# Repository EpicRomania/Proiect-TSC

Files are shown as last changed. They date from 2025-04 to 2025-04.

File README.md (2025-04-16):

# Proiect-TSC

## Block Diagram



## ESP32-C6

Microcontrolerul central care coordoneaza procesarea datelor si comunicarea cu modulele.
- Microcontroler RISC-V cu Wi-Fi 6 și Bluetooth LE.
  
**Controleaza interfetele SPI si I2C pentru restul modulelor.**

**Pentru conectarea memoriei externe, sunt folositi urmatorii pini:**

- MOSI  
- MISO  
- SCK  
- CS

**Pentru conectarea ceasului real si a senzorilor, se utilizeaza:**

- SDA  
- SCL

**Pinii de debug si programare sunt accesibili prin interfata dedicata.**

## Memorie Externa

- Conectata prin SPI (MOSI, MISO, SCK, CS). 

- Stocheaza datele e-book si firmware-ul.

## Ceas Real si Module Senzoriale

- Dispozitivele de timp real si senzorii se conecteaza pe pinii SDA si SCL.
- **DS3231** pentru data/ora precisa (RTC).  
- **BME680/BME688** pentru temperatura, umiditate, presiune si VOC (aer). 
- Aceste module asigura sincronizarea si monitorizarea mediului.

## Afisaj E-Paper 
- Controlat prin interfata SPI (linii comune cu memoria externa, dar cu semnal CS separat).  
- Are propriul circuit driver (bobina L2 si componente auxiliare).

## Stocare pe card SD
- Conectat tot pe magistrala SPI pentru extinderea posibilitatilor de stocare

 ## Butoane  
- **Reset** si **Boot** pentru controlul microcontrolerului (reprogramare, reset).
- **Change** – buton suplimentar pentru interactiuni in aplicatie.

## Management Baterie
- **MCP73831** ca incarcator LiPo (5 V din USB-C -> LiPo).  
- **MAX17048** ca monitor de nivel al bateriei (I2C).  
- **USB-C** pentru alimentare, incarcare si, la nevoie, date USB.

## Aspecte de Design

- Componentele sunt asezate astfel incat accesul la conectori sa fie relatic simplu.
- Test pads (TP) sunt disponibile pe fata placii pentru masuratori de semnal si alimentare.  
- Circuitele de protectie ESD si de filtrare sunt incluse pentru USB-C si liniile SPI. 

## Bill of Materials

| Component | Buy Link | Datasheet Link |
|---|---|---|
| ADAFRUIT_LEDCHIP-LED0603 | [Mouser](https://ro.mouser.com/c/optoelectronics/led-lighting/?m=Adafruit) | [Datasheet](https://ro.mouser.com/c/optoelectronics/led-lighting/?m=Adafruit) |
| SJ | [GrabCAD](https://grabcad.com/library/solder-jumpers-1) | [GrabCAD](https://grabcad.com/library/solder-jumpers-1) |
| ESP32_WROVER_EAGLE-LTSPICE_CC0402  | [Mouser](https://ro.mouser.com/c/passive-components/capacitors/ceramic-capacitors/?q=CC0402) | [Datasheet](https://componentsearchengine.com/Datasheets/2/CC0402MRX5R5BB106.pdf) |
| ESP32_WROVER_EAGLE-LTSPICE_RR0402  | [Mouser](https://ro.mouser.com/c/passive-components/resistors/smd-resistors-chip-resistors/?case%20code%20-%20in=0402) | [Datasheet](https://www.yageo.com/upload/media/product/products/datasheet/rchip/PYu-RC_Group_51_RoHS_L_12.pdf) |
| RCL_CPOL-EUCT3528 | [Mouser](https://ro.mouser.com/c/passive-components/antennas/?m=Linx+Technologies&series=RCL) | [Mouser](https://ro.mouser.com/c/passive-components/antennas/?m=Linx+Technologies&series=RCL) |
| 112A-TAAR-R03_ATTEND | [Comet](https://store.comet.srl.ro/Catalogue/Product/43497/) | [SnapEDA](https://www.snapeda.com/parts/112A-TAAR-R03/Attend/datasheet/) |
| DMG2305UX-7 | [DigiKey](https://www.digikey.com/en/products/detail/diodes-incorporated/DMG2305UX-7/4340666) | [Datasheet](https://www.diodes.com/assets/Datasheets/DMG2305UX.pdf) |
| 744043680IND_4828-WE-TPC_WRE | [Mouser](https://ro.mouser.com/ProductDetail/Wurth-Elektronik/744043680?qs=PGXP4M47uW6VkZq%252BkzjrHA%3D%3D)  | [Datasheet](https://www.we-online.com/components/products/datasheet/744043680.pdf) |
| BME680 | [Mouser](https://ro.mouser.com/ProductDetail/Bosch-Sensortec/BME688?qs=IS%252B4QmGtzzqQoVDscqwx3A%3D%3D) | [Datasheet](https://ro.mouser.com/datasheet/2/783/bst_bme688_fl000-2307034.pdf) |
| BUTTON_CUSYOMV1 | [Panasonic](https://industry.panasonic.com/global/en/products/control/switch/light-touch/number/evqpuj02k) | [Datasheet](https://industry.panasonic.com/global/en/downloads?tab=catalog&small_g_cd=203&part_no=EVQPUJ02K) |
| DS3231SN# | [Mouser](https://ro.mouser.com/ProductDetail/Analog-Devices-Maxim-Integrated/DS3231SN?qs=1eQvB6Dk1vhUlr8%2FOrV0Fw%3D%3D) | [Datasheet](https://ro.mouser.com/datasheet/2/609/DS3231-3421123.pdf) |
| ESP32-C6-WROOM-1-N8 | [Mouser](https://ro.mouser.com/ProductDetail/Espressif-Systems/ESP32-C6-WROOM-1-N8?qs=8Wlm6%252BaMh8ST02Gmwp74cw%3D%3D) | [Datasheet](https://ro.mouser.com/datasheet/2/891/Espressif_ESP32_C6_WROOM_1__Datasheet_V0_1_PRELIMI-3239987.pdf) |
| ESP32C6_VARISTORCN1812 | [Mouser](https://ro.mouser.com/c/circuit-protection/varistors/?package=1812) | [Mouser](https://ro.mouser.com/c/circuit-protection/varistors/?package=1812) |
| SD0805S020S1R0 | [Mouser](https://ro.mouser.com/ProductDetail/KYOCERA-AVX/SD0805S020S1R0?qs=jCA%252BPfw4LHbpkAoSnwrdjw%3D%3D)  | [Datasheet](https://ro.mouser.com/datasheet/2/40/schottky-3165252.pdf) |
| MCP73831 | [Mouser](https://ro.mouser.com/ProductDetail/Microchip-Technology/MCP73831T-2ATI-OT?qs=yUQqVecv4qsZbioEUu%252B83g%3D%3D) | [Datasheet](https://ro.mouser.com/datasheet/2/268/MCP73831_Family_Data_Sheet_DS20001984H-3441711.pdf) |

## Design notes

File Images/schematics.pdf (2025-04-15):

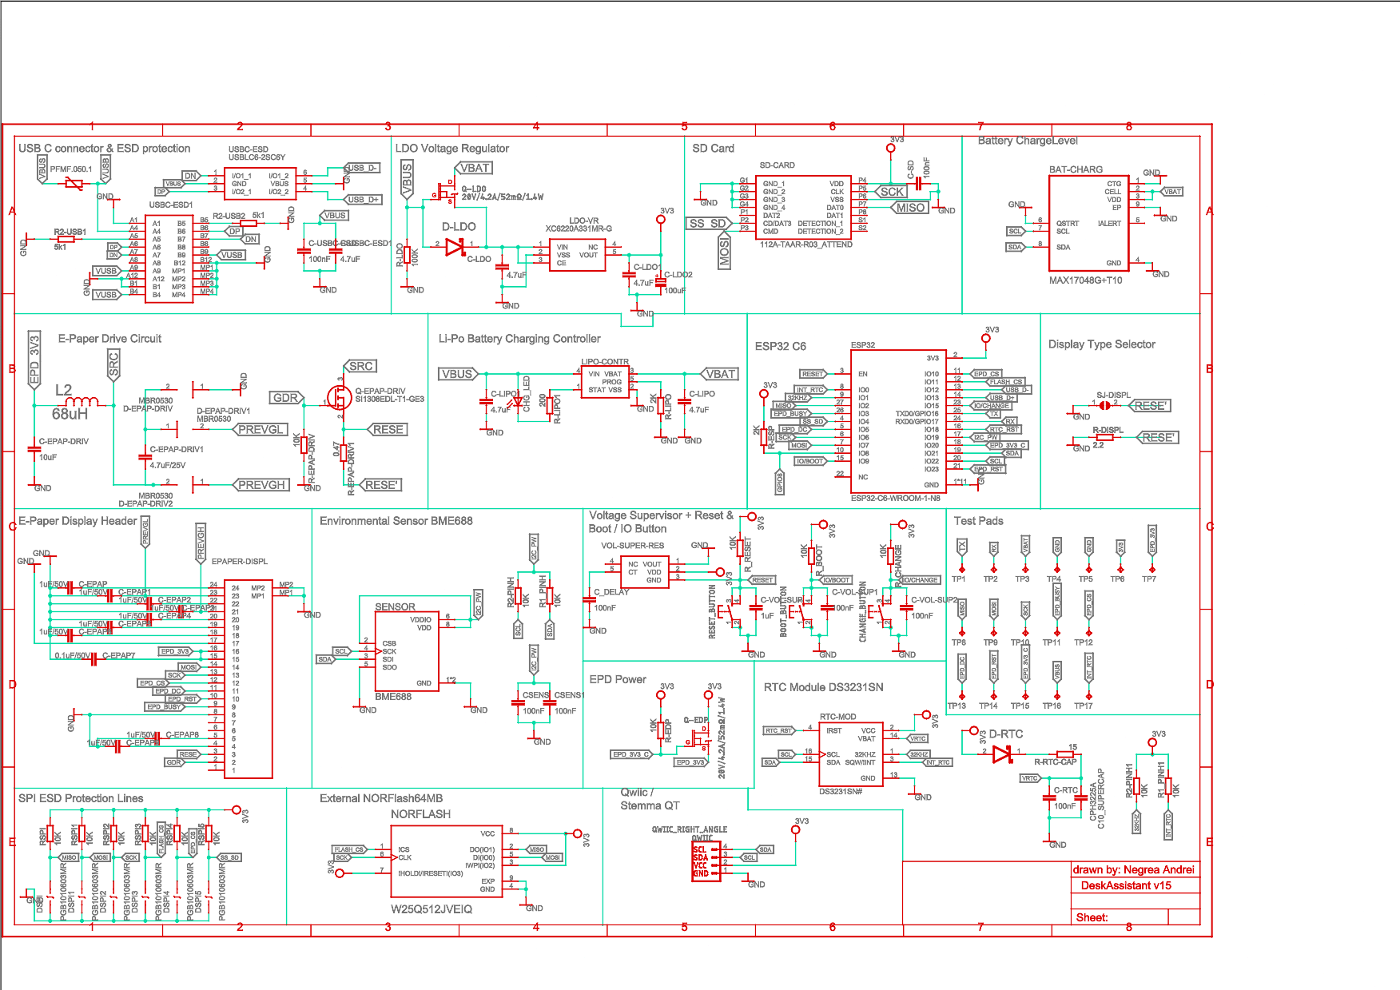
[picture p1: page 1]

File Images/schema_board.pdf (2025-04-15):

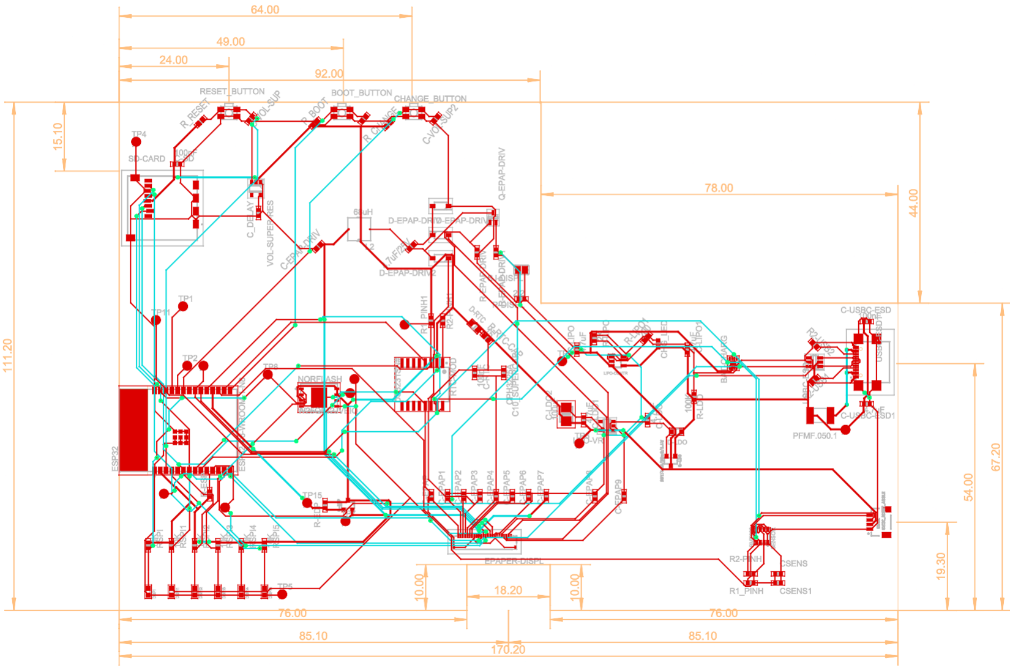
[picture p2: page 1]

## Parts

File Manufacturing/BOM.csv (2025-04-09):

Qty | Value | Device | Package | Parts | Description | ARROW_PART_NUMBER | ARROW_PRICE-STOCK | AVAILABILITY | CENTROID_NOT_SPECIFIED | CHECK_PRICES | COPYRIGHT | DATASHEET | DESCRIPTION | DIGIKEY_DESCRIPTION | DIGIKEY_PART_NUMBER | HEIGHT | LEAD_FREE | MANUFACTURER_NAME | MANUFACTURER_PART_NUMBER | MF | MFR_NAME | MOUSER_PART_NUMBER | MOUSER_PRICE-STOCK | MOUSER_TESTING_PART_NUMBER | MOUSER_TESTING_PRICE-STOCK | MP | MPN | PACKAGE | POPULARITY | PREFIX | PRICE | PROD_ID | PURCHASE-URL | ROHS | SNAPEDA_LINK | SPICEMODEL | SPICEPREFIX | TEMPERATURE_RANGE_HIGH | TEMPERATURE_RANGE_LOW | TP_SIGNAL_NAME | VALUE
1 |  | ADAFRUIT_LEDCHIP-LED0603 | ADAFRUIT_CHIP-LED0603 | CHG_LED | LED
1 |  | SJ | SJ | SJ-DISPL | SMD solder JUMPER |  |  |  |  |  |  |  |  |  |  |  |  |  |  |  |  |  |  |  |  |  |  |  | 3
1 | 0.1uF/50V | ESP32_WROVER_EAGLE-LTSPICE_CC0402 | ESP32_WROVER_EAGLE-LTSPICE_C0402 | C-EPAP7 | CAPACITOR, European symbol |  |  |  |  |  |  |  |  |  |  |  |  |  |  |  |  |  |  |  |  |  |  |  |  |  |  |  |  |  |  | NONE | C
1 | 0.47 | ESP32_WROVER_EAGLE-LTSPICE_RR0402 | ESP32_WROVER_EAGLE-LTSPICE_R0402 | R-EPAP-DRIV1 | RESISTOR, European symbol |  |  |  |  |  |  |  |  |  |  |  |  |  |  |  |  |  |  |  |  |  |  |  |  |  |  |  |  |  |  | NONE | R
1 | 100K | ESP32_WROVER_EAGLE-LTSPICE_RR0402 | ESP32_WROVER_EAGLE-LTSPICE_R0402 | R-LDO | RESISTOR, European symbol |  |  |  |  |  |  |  |  |  |  |  |  |  |  |  |  |  |  |  |  |  |  |  |  |  |  |  |  |  |  | NONE | R
8 | 100nF | ESP32_WROVER_EAGLE-LTSPICE_CC0402 | ESP32_WROVER_EAGLE-LTSPICE_C0402 | C-RTC, C-SD, C-USBC-ESD, C-VOL-SUP1, C-VOL-SUP2, CSENS, CSENS1, C_DELAY | CAPACITOR, European symbol |  |  |  |  |  |  |  |  |  |  |  |  |  |  |  |  |  |  |  |  |  |  |  |  |  |  |  |  |  |  | NONE | C
1 | 100uF | RCL_CPOL-EUCT3528 | RCL_CT3528 | C-LDO2 | POLARIZED CAPACITOR, European symbol |  |  |  |  |  |  |  |  |  |  |  |  |  |  |  |  |  |  |  |  |  |  |  | 0 |  |  |  |  |  |  |  | C
15 | 10K | ESP32_WROVER_EAGLE-LTSPICE_RR0402 | ESP32_WROVER_EAGLE-LTSPICE_R0402 | R-EDP, R-EPAP-DRIV, R1_PINH, R1_PINH1, R2-PINH, R2-PINH1, RSPI, RSPI1, RSPI2, RSPI3, RSPI4, RSPI5, R_BOOT, R_CHANGE, R_RESET | RESISTOR, European symbol |  |  |  |  |  |  |  |  |  |  |  |  |  |  |  |  |  |  |  |  |  |  |  |  |  |  |  |  |  |  | NONE | R
1 | 10uF | ESP32_WROVER_EAGLE-LTSPICE_CC0402 | ESP32_WROVER_EAGLE-LTSPICE_C0402 | C-EPAP-DRIV | CAPACITOR, European symbol |  |  |  |  |  |  |  |  |  |  |  |  |  |  |  |  |  |  |  |  |  |  |  |  |  |  |  |  |  |  | NONE | C
1 | 112A-TAAR-R03_ATTEND | 112A-TAAR-R03_ATTEND | 112ATAARR03ATTEND | SD-CARD | Micro SD Card Socket, Push-Push Type, Top Mount, SMT, H=1.83mm, 10u |  |  |  |  |  |  |  | Micro SD Card Socket | Push-Push Type | Top Mount | SMT | H=1.83mm | 10u |  |  | 1.9mm |  | ATTEND | 112A-TAAR-R03 ATTEND
1 | 15 | ESP32_WROVER_EAGLE-LTSPICE_RR0402 | ESP32_WROVER_EAGLE-LTSPICE_R0402 | R-RTC-CAP | RESISTOR, European symbol |  |  |  |  |  |  |  |  |  |  |  |  |  |  |  |  |  |  |  |  |  |  |  |  |  |  |  |  |  |  | NONE | R
1 | 1uF | ESP32_WROVER_EAGLE-LTSPICE_CC0402 | ESP32_WROVER_EAGLE-LTSPICE_C0402 | C-VOL-SUP | CAPACITOR, European symbol |  |  |  |  |  |  |  |  |  |  |  |  |  |  |  |  |  |  |  |  |  |  |  |  |  |  |  |  |  |  | NONE | C
9 | 1uF/50V | ESP32_WROVER_EAGLE-LTSPICE_CC0402 | ESP32_WROVER_EAGLE-LTSPICE_C0402 | C-EPAP, C-EPAP1, C-EPAP2, C-EPAP3, C-EPAP4, C-EPAP5, C-EPAP6, C-EPAP8, C-EPAP9 | CAPACITOR, European symbol |  |  |  |  |  |  |  |  |  |  |  |  |  |  |  |  |  |  |  |  |  |  |  |  |  |  |  |  |  |  | NONE | C
1 | 2.2 | ESP32_WROVER_EAGLE-LTSPICE_RR0402 | ESP32_WROVER_EAGLE-LTSPICE_R0402 | R-DISPL | RESISTOR, European symbol |  |  |  |  |  |  |  |  |  |  |  |  |  |  |  |  |  |  |  |  |  |  |  |  |  |  |  |  |  |  | NONE | R
1 | 200 | ESP32_WROVER_EAGLE-LTSPICE_RR0402 | ESP32_WROVER_EAGLE-LTSPICE_R0402 | R-LIPO1 | RESISTOR, European symbol |  |  |  |  |  |  |  |  |  |  |  |  |  |  |  |  |  |  |  |  |  |  |  |  |  |  |  |  |  |  | NONE | R
2 | 20V/4.2A/52mO/1.4W | ESP32_WROVER_SPARKFUN-DISCRETESEMI_MOSFET_PCH-DMG2305UX-7 | ESP32_WROVER_SPARKFUN-DISCRETESEMI_SOT23-3 | Q-EDP, Q-LDO | P-channel MOSFETs |  |  |  |  |  |  |  |  |  |  |  |  |  |  |  |  |  |  |  |  |  |  |  |  |  |  | TRAN-14388 |  |  |  |  |  |  |  |  | 20V/4.2A/52mO/1.4W
2 | 2K | ESP32_WROVER_EAGLE-LTSPICE_RR0402 | ESP32_WROVER_EAGLE-LTSPICE_R0402 | R-ESP, R-LIPO | RESISTOR, European symbol |  |  |  |  |  |  |  |  |  |  |  |  |  |  |  |  |  |  |  |  |  |  |  |  |  |  |  |  |  |  | NONE | R
5 | 4.7uF | ESP32_WROVER_EAGLE-LTSPICE_CC0402 | ESP32_WROVER_EAGLE-LTSPICE_C0402 | C-LDO, C-LDO1, C-LIPO, C-LIPO1, C-USBC-ESD1 | CAPACITOR, European symbol |  |  |  |  |  |  |  |  |  |  |  |  |  |  |  |  |  |  |  |  |  |  |  |  |  |  |  |  |  |  | NONE | C
1 | 4.7uF/25V | ESP32_WROVER_EAGLE-LTSPICE_CC0402 | ESP32_WROVER_EAGLE-LTSPICE_C0402 | C-EPAP-DRIV1 | CAPACITOR, European symbol |  |  |  |  |  |  |  |  |  |  |  |  |  |  |  |  |  |  |  |  |  |  |  |  |  |  |  |  |  |  | NONE | C
2 | 5k1 | ESP32_WROVER_EAGLE-LTSPICE_RR0402 | ESP32_WROVER_EAGLE-LTSPICE_R0402 | R2-USB1, R2-USB2 | RESISTOR, European symbol |  |  |  |  |  |  |  |  |  |  |  |  |  |  |  |  |  |  |  |  |  |  |  |  |  |  |  |  |  |  | NONE | R
1 | 68uH | 744043680IND_4828-WE-TPC_WRE | IND_4828-WE-TPC_WRE | L2 |  |  |  |  |  |  | Copyright (C) 2024 Ultra Librarian. All rights reserved. |  |  |  |  |  |  |  | 744043680 |  | Wurth Electronics
1 | BME688 | ESP32_WROVER_BME680_BME680 | ESP32_WROVER_BME680_PSON80P300X300X100-8N | SENSOR | Integrated Environmental Unit |  |  | Unavailable |  |  |  |  | Integrated Environmental Unit |  |  |  |  |  |  | Bosch Sensortec |  |  |  |  |  | BME680 |  | LGA-8 Bosch Tools |  |  | None
1 | BOOT_BUTTON | BUTTON_CUSYOMV1 | MYBUTTON | BOOT_BUTTON
1 | C10_SUPERCAP | ESP32_WROVER_EAGLE-LTSPICE_CC0402 | ESP32_WROVER_EAGLE-LTSPICE_C0402 | CPH3225A | CAPACITOR, European symbol |  |  |  |  |  |  |  |  |  |  |  |  |  |  |  |  |  |  |  |  |  |  |  |  |  |  |  |  |  |  | NONE | C
1 | CHANGE_BUTTON | BUTTON_CUSYOMV1 | MYBUTTON | CHANGE_BUTTON
1 | DS3231SN# | DS3231SN# | SOIC127P1032X265-16N | RTC-MOD | Real Time Clock Serial 16-Pin SOIC W T/R Check availability |  |  | In Stock |  | https://www.snapeda.com/parts/DS3231SN%23/Analog+Devices/view-part/?ref=eda |  |  | Extremely Accurate I²C-Integrated RTC/TCXO/Crystal |  |  |  |  |  |  | Analog Devices |  |  |  |  |  | DS3231SN# |  | SOIC-16 Maxim |  |  | None |  | https://www.snapeda.com/api/url_track_click_mouser/?unipart_id=99048&manufacturer=Analog Devices&part_name=DS3231SN#&search_term=None |  | https://www.snapeda.com/parts/DS3231SN%23/Analog+Devices/view-part/?ref=snap
1 | ESP32-C6-WROOM-1-N8 | ESP32-C6-WROOM-1-N8 | XCVR_ESP32-C6-WROOM-1-N8 | ESP32 | Check availability |  |  | In Stock |  | https://www.snapeda.com/parts/ESP32-C6-WROOM-1-N8/Espressif+Systems/view-part/?ref=eda |  |  | Multiprotocol Modules ESP32-C6 module | Wi-Fi 6 in 2.4 GHz band | Bluetooth 5 | Zigbee 3.0 and Thread. ESP34-WROOM Compatible - ENGINEERING SAMPLE |  |  |  |  |  |  | Espressif Systems |  |  |  |  |  | ESP32-C6-WROOM-1-N8 |  | None |  |  | None |  |  |  | https://www.snapeda.com/parts/ESP32-C6-WROOM-1-N8/Espressif+Systems/view-part/?ref=snap
1 | ESP32C6_VARISTORCN1812 | ESP32C6_VARISTORCN1812 | ESP32C6_VARISTOR_CT/CN1812 | PFMF.050.1 | VARISTOR |  |  |  |  |  |  |  |  |  |  |  |  |  |  |  |  |  |  |  |  |  |  |  | 0
2 | ESP32_WROVER_AVX---SD0805S020S1R0_AVX_SD0805S020S1R0_0_0AVX_SD0805S020S1R0_0_0 | ESP32_WROVER_AVX---SD0805S020S1R0_AVX_SD0805S020S1R0_0_0AVX_SD0805S020S1R0_0_0 | ESP32_WROVER_AVX---SD0805S020S1R0_AVX_SD0805S020S1R0_0 | D-LDO, D-RTC | Schottky Barrier Rectifier Diode |  |  |  | No |  |  | http://datasheets.avx.com/schottky.pdf |  | DIODE SCHOTTKY 20V 1A 0805 | 478-7800-1-ND |  | yes |  |  | AVX |  | 581-SD0805S020S1R0 |  |  |  |  |  | 0805 (2012 metric) |  | D |  |  |  | yes |  |  |  | +125°C | -55°C
1 | ESP32_WROVER_SPARKFUN-IC-POWER_MCP73831 | ESP32_WROVER_SPARKFUN-IC-POWER_MCP73831 | ESP32_WROVER_SPARKFUN-IC-POWER_SOT23-5 | LIPO-CONTR | MCP73831T Li-Ion, Li-Pol Controller |  |  |  |  |  |  |  |  |  |  |  |  |  |  |  |  |  |  |  |  |  |  |  |  |  |  | IC-09995
1 | FH34SRJ-24S-0.5SH_99_ | FH34SRJ-24S-0.5SH_99_ | FH34SRJ24S05SH99 | EPAPER-DISPL | (0.50mm) Surface Mount, Right Angle |  |  |  |  |  |  |  | 24 Position FFC | FPC Connector Contacts | (0.50mm) Surface Mount | Right Angle |  |  | 1.1mm |  | Hirose | FH34SRJ-24S-0.5SH(99) |  |  | 798-FH34SRJ24S05SH99 | https://www.mouser.co.uk/ProductDetail/Hirose-Connector/FH34SRJ-24S-0.5SH99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
1 | MAX17048G+T10 | MAX17048G+T10 | SON50P200X200X80-9N | BAT-CHARG | Check availability |  |  | In Stock |  | https://www.snapeda.com/parts/MAX17048G+T10/Analog+Devices/view-part/?ref=eda |  |  | 3µA 1-Cell/2-Cell Fuel Gauge with ModelGauge |  |  |  |  |  |  | Analog Devices |  |  |  |  |  | MAX17048G+T10 |  | TDFN-8 Maxim |  |  | None |  | https://www.snapeda.com/api/url_track_click_mouser/?unipart_id=329239&manufacturer=Analog Devices&part_name=MAX17048G+T10&search_term=None |  | https://www.snapeda.com/parts/MAX17048G+T10/Analog+Devices/view-part/?ref=snap
3 | MBR0530 | MBR0530 | SOD3716X135N | D-EPAP-DRIV, D-EPAP-DRIV1, D-EPAP-DRIV2 | ON SEMICONDUCTOR - MBR0530 - DIODE, SCHOTTKY, 0.5A, 30V, SOD-123 |  |  | In Stock |  | https://www.snapeda.com/parts/MBR0530/Onsemi/view-part/?ref=eda |  |  | Diode Schottky 30 V 500mA Surface Mount SOD-123 |  |  |  |  |  |  | ON Semiconductor |  |  |  |  |  | MBR0530 |  | SOD-123-2 ON Semiconductor |  |  | None |  | https://www.snapeda.com/api/url_track_click_mouser/?unipart_id=179458&manufacturer=ON Semiconductor&part_name=MBR0530&search_term=None |  | https://www.snapeda.com/parts/MBR0530/Onsemi/view-part/?ref=snap
6 | PGB1010603MR | PGB1010603MR | DIOC1608X36N | DSPI, DSPI1, DSPI2, DSPI3, DSPI4, DSPI5 | Check availability |  |  | In Stock |  | https://www.snapeda.com/parts/PGB1010603MR/Littelfuse/view-part/?ref=eda |  |  | 150V (Typ) Clamp - Ipp Tvs Diode Surface Mount 0603 (1608 Metric) |  |  |  |  |  |  | Littelfuse Inc. |  |  |  |  |  | PGB1010603MR |  | 0603 Littelfuse Inc. |  |  | None |  | https://www.snapeda.com/api/url_track_click_mouser/?unipart_id=5659453&manufacturer=Littelfuse Inc.&part_name=PGB1010603MR&search_term=None |  | https://www.snapeda.com/parts/PGB1010603MR/Littelfuse/view-part/?ref=snap
1 | QWIIC_RIGHT_ANGLE | QWIIC_CONNECTORJS-1MM | JST04_1MM_RA | QWIIC | SparkFun I2C Standard Qwiic Connector |  |  |  |  |  |  |  |  |  |  |  |  |  |  |  |  |  |  |  |  |  |  |  |  |  |  | CONN-13694 |  |  |  |  |  |  |  |  | QWIIC_RIGHT_ANGLE
1 | RESET_BUTTON | BUTTON_CUSYOMV1 | MYBUTTON | RESET_BUTTON
1 | SAMACSYS_PARTS_USB4110-GF-A | SAMACSYS_PARTS_USB4110-GF-A | SAMACSYS_PARTS_USB4110GFA | USBC-ESD1 | CONN USB 2.0 TYPE-C R/A SMT |  |  |  |  |  |  |  | CONN USB 2.0 TYPE-C R/A SMT |  |  | 3.26mm |  | GCT (GLOBAL CONNECTOR TECHNOLOGY) | USB4110-GF-A |  |  | 640-USB4110-GF-A | https://www.mouser.co.uk/ProductDetail/GCT/USB4110-GF-A?qs=KUoIvG%2F9IlYiZvIXQjyJeA%3D%3D
1 | SI1308EDL-T1-GE3 | SI1308EDL-T1-GE3 | SOT65P210X110-3N | Q-EPAP-DRIV | MOSFET N-Ch 30V 1.5A TrenchFET SC70 Vishay Si1308EDL-T1-GE3 N-channel MOSFET Transistor, 1.5 A, 30 V, 3-Pin SC-70 |  |  | In Stock |  | https://www.snapeda.com/parts/SI1308EDL-T1-GE3/Vishay+Siliconix/view-part/?ref=eda |  |  | Si1308EDL-T1-GE3 N-channel MOSFET Transistor | 1.5 A | 30 V | 3-Pin SC-70 | Siliconix / Vishay SI1308EDL-T1-GE3 |  |  |  |  |  |  | Vishay Siliconix |  |  |  |  |  | SI1308EDL-T1-GE3 |  | SOT-323 Vishay Semiconductor |  |  | None |  | https://www.snapeda.com/api/url_track_click_mouser/?unipart_id=274603&manufacturer=Vishay Siliconix&part_name=SI1308EDL-T1-GE3&search_term=None |  | https://www.snapeda.com/parts/SI1308EDL-T1-GE3/Vishay+Siliconix/view-part/?ref=snap
17 | TPTP20R | TPTP20R | TP20R | TP1, TP2, TP3, TP4, TP5, TP6, TP7, TP8, TP9, TP10, TP11, TP12, TP13, TP14, TP15, TP16, TP17 | Test pad |  |  |  |  |  |  |  |  |  |  |  |  |  |  |  |  |  |  |  |  |  |  |  | 2
1 | USBLC6-2SC6Y | USBLC6-2SC6Y | SOT95P280X145-6N | USBC-ESD | Low Cap. ESD Protection Auto SOT-23-6 STMicroelectronics USBLC6-2SC6Y, Dual Uni-Directional TVS Diode Array, 6-Pin SOT-23 |  |  | In Stock |  | https://www.snapeda.com/parts/USBLC6-2SC6Y/STMicroelectronics/view-part/?ref=eda |  |  | 17V Clamp 5A (8/20µs) Ipp Tvs Diode Surface Mount SOT-23-6 |  |  |  |  |  |  | STMicroelectronics |  |  |  |  |  | USBLC6-2SC6Y |  | SOT-23-6 STMicroelectronics |  |  | None |  |  |  | https://www.snapeda.com/parts/USBLC6-2SC6Y/STMicroelectronics/view-part/?ref=snap
1 | VOL-SUPER-RES | BD5229G-TR | SOT95P280X125-5N | VOL-SUPER | Voltage Detector with Adjustable Delay Time: CMOS processes are utilized to develop high precision, low current consumption CMOS reset ICs that allow arbitrary setting of the delay time. The extensive lineup includes both Nch Open Drain and CMOS output types in a wide range of detection voltages (from 2.3V to 6.0V, in 0.1V steps), enabling selection of the ideal solution based on customer requirements. In addition, the entire series is of course both lead-free and RoHS-compliant. |  |  |  |  |  |  |  | Voltage Detector with Adjustable Delay Time: CMOS processes are utilized to develop high precision | low current consumption CMOS reset ICs that allow arbitrary setting of the delay time. The extensive lineup includes both Nch Open Drain and CMOS output types in a wide range of detection voltages (from 2.3V to 6.0V | in 0.1V steps) | enabling selection of the ideal solution based on customer requirements. In addition | the entire series is of course both lead-free and RoHS-compliant. |  |  | 1.25mm |  | ROHM Semiconductor | BD5229G-TR |  |  | 755-BD5229G-TR | https://www.mouser.co.uk/ProductDetail/ROHM-Semiconductor/BD5229G-TR?qs=4kLU8WoGk0vvnhrrYwdszw%3D%3D
1 | W25Q512JVEIQ | W25Q512JVEIQ | SON127P600X800X80-9N | NORFLASH | Check availability |  |  | In Stock |  | https://www.snapeda.com/parts/W25Q512JVEIQ/Winbond+Electronics/view-part/?ref=eda |  |  | FLASH - NOR Memory IC 512Mb (64M x 8) SPI - Quad I/O 133 MHz 8-WSON (8x6) |  |  |  |  |  |  | Winbond Electronics |  |  |  |  |  | W25Q512JVEIQ |  | Package |  |  | None |  |  |  | https://www.snapeda.com/parts/W25Q512JVEIQ/Winbond+Electronics/view-part/?ref=snap
1 | XC6220A331MR-G | XC6220A331MR-G | SOT95P280X120-5N | LDO-VR | LDO Voltage Regulators |  |  |  |  |  |  |  | LDO Voltage Regulators |  |  | 1.2mm |  | Torex | XC6220A331MR-G |  |  | 865-XC6220A331MR-G | https://www.mouser.co.uk/ProductDetail/Torex-Semiconductor/XC6220A331MR-G?qs=AsjdqWjXhJ8ZSWznL1J0gg%3D%3D

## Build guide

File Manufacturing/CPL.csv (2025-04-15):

BAT-CHARG | 134.19 | 54.07 | 90.00 | MAX17048G+T10 | SON50P200X200X80-9N
BOOT_BUTTON | 48.69 | 108.82 | 180.00 | BOOT_BUTTON | MYBUTTON
C-EPAP | 68.24 | 24.97 | 90.00 | 1uF/50V | ESP32_WROVER_EAGLE-LTSPICE_C0402
C-EPAP-DRIV | 43.58 | 79.57 | 225.00 | 10uF | ESP32_WROVER_EAGLE-LTSPICE_C0402
C-EPAP-DRIV1 | 63.90 | 79.57 | 225.00 | 4.7uF/25V | ESP32_WROVER_EAGLE-LTSPICE_C0402
C-EPAP1 | 71.78 | 24.97 | 90.00 | 1uF/50V | ESP32_WROVER_EAGLE-LTSPICE_C0402
C-EPAP2 | 75.32 | 24.97 | 90.00 | 1uF/50V | ESP32_WROVER_EAGLE-LTSPICE_C0402
C-EPAP3 | 78.86 | 24.97 | 90.00 | 1uF/50V | ESP32_WROVER_EAGLE-LTSPICE_C0402
C-EPAP4 | 82.40 | 24.97 | 90.00 | 1uF/50V | ESP32_WROVER_EAGLE-LTSPICE_C0402
C-EPAP5 | 85.94 | 24.97 | 90.00 | 1uF/50V | ESP32_WROVER_EAGLE-LTSPICE_C0402
C-EPAP6 | 89.48 | 24.97 | 90.00 | 1uF/50V | ESP32_WROVER_EAGLE-LTSPICE_C0402
C-EPAP7 | 93.37 | 24.97 | 90.00 | 0.1uF/50V | ESP32_WROVER_EAGLE-LTSPICE_C0402
C-EPAP8 | 103.99 | 24.97 | 90.00 | 1uF/50V | ESP32_WROVER_EAGLE-LTSPICE_C0402
C-EPAP9 | 110.34 | 24.97 | 90.00 | 1uF/50V | ESP32_WROVER_EAGLE-LTSPICE_C0402
C-LDO | 115.48 | 41.62 | 90.00 | 4.7uF | ESP32_WROVER_EAGLE-LTSPICE_C0402
C-LDO1 | 101.51 | 41.62 | 90.00 | 4.7uF | ESP32_WROVER_EAGLE-LTSPICE_C0402
C-LDO2 | 97.70 | 42.89 | 90.00 | 100uF | RCL_CT3528
C-LIPO | 100.03 | 57.04 | 90.00 | 4.7uF | ESP32_WROVER_EAGLE-LTSPICE_C0402
C-LIPO1 | 124.16 | 57.04 | 90.00 | 4.7uF | ESP32_WROVER_EAGLE-LTSPICE_C0402
C-RTC | 77.69 | 51.96 | 270.00 | 100nF | ESP32_WROVER_EAGLE-LTSPICE_C0402
C-SD | 12.70 | 97.63 | 0.00 | 100nF | ESP32_WROVER_EAGLE-LTSPICE_C0402
C-USBC-ESD | 163.40 | 63.19 | 0.00 | 100nF | ESP32_WROVER_EAGLE-LTSPICE_C0402
C-USBC-ESD1 | 163.40 | 45.18 | 0.00 | 4.7uF | ESP32_WROVER_EAGLE-LTSPICE_C0402
C-VOL-SUP | 28.80 | 107.55 | 230.00 | 1uF | ESP32_WROVER_EAGLE-LTSPICE_C0402
C-VOL-SUP1 | 53.50 | 107.55 | 230.00 | 100nF | ESP32_WROVER_EAGLE-LTSPICE_C0402
C-VOL-SUP2 | 69.20 | 107.55 | 230.00 | 100nF | ESP32_WROVER_EAGLE-LTSPICE_C0402
CHANGE_BUTTON | 64.39 | 108.82 | 180.00 | CHANGE_BUTTON | MYBUTTON
CHG_LED | 117.81 | 58.31 | 0.00 |  | ADAFRUIT_CHIP-LED0603
CPH3225A | 84.04 | 51.96 | 270.00 | C10_SUPERCAP | ESP32_WROVER_EAGLE-LTSPICE_C0402
CSENS | 144.00 | 8.00 | 0.00 | 100nF | ESP32_WROVER_EAGLE-LTSPICE_C0402
CSENS1 | 144.00 | 6.00 | 0.00 | 100nF | ESP32_WROVER_EAGLE-LTSPICE_C0402
C_DELAY | 30.45 | 86.94 | 270.00 | 100nF | ESP32_WROVER_EAGLE-LTSPICE_C0402
D-EPAP-DRIV | 70.25 | 88.46 | 180.00 | MBR0530 | SOD3716X135N
D-EPAP-DRIV1 | 70.25 | 82.11 | 0.00 | MBR0530 | SOD3716X135N
D-EPAP-DRIV2 | 70.25 | 77.03 | 180.00 | MBR0530 | SOD3716X135N
D-LDO | 121.83 | 39.08 | 0.00 | ESP32_WROVER_AVX---SD0805S020S1R0_AVX_SD0805S020S1R0_0_0AVX_SD0805S020S1R0_0_0 | ESP32_WROVER_AVX---SD0805S020S1R0_AVX_SD0805S020S1R0_0
D-RTC | 77.69 | 62.12 | 135.00 | ESP32_WROVER_AVX---SD0805S020S1R0_AVX_SD0805S020S1R0_0_0AVX_SD0805S020S1R0_0_0 | ESP32_WROVER_AVX---SD0805S020S1R0_AVX_SD0805S020S1R0_0
DSPI | 6.35 | 4.08 | 90.00 | PGB1010603MR | DIOC1608X36N
DSPI1 | 11.43 | 4.08 | 90.00 | PGB1010603MR | DIOC1608X36N
DSPI2 | 16.51 | 4.08 | 90.00 | PGB1010603MR | DIOC1608X36N
DSPI3 | 21.59 | 4.08 | 90.00 | PGB1010603MR | DIOC1608X36N
DSPI4 | 26.67 | 4.08 | 90.00 | PGB1010603MR | DIOC1608X36N
DSPI5 | 31.75 | 4.08 | 90.00 | PGB1010603MR | DIOC1608X36N
EPAPER-DISPL | 79.86 | 15.01 | 0.00 | FH34SRJ-24S-0.5SH_99_ | FH34SRJ24S05SH99
ESP32 | 15.97 | 39.37 | 90.00 | ESP32-C6-WROOM-1-N8 | XCVR_ESP32-C6-WROOM-1-N8
L2 | 52.47 | 83.38 | 180.00 | 68uH | IND_4828-WE-TPC_WRE
LDO-VR | 106.59 | 40.35 | 180.00 | XC6220A331MR-G | SOT95P280X120-5N
LIPO-CONTR | 108.92 | 54.50 | 270.00 | ESP32_WROVER_SPARKFUN-IC-POWER_MCP73831 | ESP32_WROVER_SPARKFUN-IC-POWER_SOT23-5
NORFLASH | 43.69 | 46.56 | 0.00 | W25Q512JVEIQ | SON127P600X800X80-9N
PFMF.050.1 | 153.24 | 42.64 | 180.00 | ESP32C6_VARISTORCN1812 | ESP32C6_VARISTOR_CT/CN1812
Q-EDP | 50.00 | 23.05 | 0.00 | 20V/4.2A/52mΩ/1.4W | ESP32_WROVER_SPARKFUN-DISCRETESEMI_SOT23-3
Q-EPAP-DRIV | 81.71 | 85.92 | 90.00 | SI1308EDL-T1-GE3 | SOT65P210X110-3N
Q-LDO | 120.56 | 32.68 | 180.00 | 20V/4.2A/52mΩ/1.4W | ESP32_WROVER_SPARKFUN-DISCRETESEMI_SOT23-3
QWIIC | 165.88 | 19.30 | 90.00 | QWIIC_RIGHT_ANGLE | JST04_1MM_RA
R-DISPL | 87.92 | 68.14 | 180.00 | 2.2 | ESP32_WROVER_EAGLE-LTSPICE_R0402
R-EDP | 45.00 | 23.00 | 270.00 | 10K | ESP32_WROVER_EAGLE-LTSPICE_R0402
R-EPAP-DRIV | 78.22 | 78.30 | 270.00 | 10K | ESP32_WROVER_EAGLE-LTSPICE_R0402
R-EPAP-DRIV1 | 82.36 | 78.30 | 270.00 | 0.47 | ESP32_WROVER_EAGLE-LTSPICE_R0402
R-ESP | 19.78 | 25.40 | 90.00 | 2K | ESP32_WROVER_EAGLE-LTSPICE_R0402
R-LDO | 125.64 | 46.70 | 270.00 | 100K | ESP32_WROVER_EAGLE-LTSPICE_R0402
R-LIPO | 103.84 | 59.58 | 90.00 | 2K | ESP32_WROVER_EAGLE-LTSPICE_R0402
R-LIPO1 | 115.27 | 59.58 | 50.00 | 200 | ESP32_WROVER_EAGLE-LTSPICE_R0402
R-RTC-CAP | 80.23 | 59.58 | 135.00 | 15 | ESP32_WROVER_EAGLE-LTSPICE_R0402
R1_PINH | 138.00 | 6.00 | 0.00 | 10K | ESP32_WROVER_EAGLE-LTSPICE_R0402
R1_PINH1 | 68.17 | 63.39 | 90.00 | 10K | ESP32_WROVER_EAGLE-LTSPICE_R0402
R2-PINH | 138.00 | 8.00 | 0.00 | 10K | ESP32_WROVER_EAGLE-LTSPICE_R0402
R2-PINH1 | 70.70 | 63.39 | 90.00 | 10K | ESP32_WROVER_EAGLE-LTSPICE_R0402
R2-USB1 | 151.97 | 50.26 | 45.00 | 5k1 | ESP32_WROVER_EAGLE-LTSPICE_R0402
R2-USB2 | 151.97 | 58.11 | 135.00 | 5k1 | ESP32_WROVER_EAGLE-LTSPICE_R0402
RESET_BUTTON | 23.99 | 108.82 | 180.00 | RESET_BUTTON | MYBUTTON
RSPI | 6.35 | 14.24 | 90.00 | 10K | ESP32_WROVER_EAGLE-LTSPICE_R0402
RSPI1 | 11.43 | 14.24 | 90.00 | 10K | ESP32_WROVER_EAGLE-LTSPICE_R0402
RSPI2 | 16.51 | 14.24 | 90.00 | 10K | ESP32_WROVER_EAGLE-LTSPICE_R0402
RSPI3 | 21.59 | 14.24 | 90.00 | 10K | ESP32_WROVER_EAGLE-LTSPICE_R0402
RSPI4 | 26.67 | 14.24 | 90.00 | 10K | ESP32_WROVER_EAGLE-LTSPICE_R0402
RSPI5 | 31.75 | 14.24 | 90.00 | 10K | ESP32_WROVER_EAGLE-LTSPICE_R0402
RTC-MOD | 66.26 | 49.42 | 270.00 | DS3231SN# | SOIC127P1032X265-16N
R_BOOT | 42.83 | 106.61 | 45.00 | 10K | ESP32_WROVER_EAGLE-LTSPICE_R0402
R_CHANGE | 58.83 | 106.31 | 45.00 | 10K | ESP32_WROVER_EAGLE-LTSPICE_R0402
R_RESET | 17.83 | 106.91 | 45.00 | 10K | ESP32_WROVER_EAGLE-LTSPICE_R0402
SD-CARD | 9.63 | 88.06 | 270.00 | 112A-TAAR-R03_ATTEND | 112ATAARR03ATTEND
SENSOR | 140.52 | 16.28 | 270.00 | BME688 | ESP32_WROVER_BME680_PSON80P300X300X100-8N
SJ-DISPL | 87.92 | 74.49 | 180.00 |  | SJ
TP1 | 13.96 | 66.52 | 0.00 | TPTP20R | TP20R
TP10 | 50.49 | 47.52 | 0.00 | TPTP20R | TP20R
TP11 | 8.04 | 63.52 | 0.00 | TPTP20R | TP20R
TP12 | 23.14 | 22.52 | 0.00 | TPTP20R | TP20R
TP13 | 9.79 | 25.52 | 0.00 | TPTP20R | TP20R
TP14 | 18.44 | 53.52 | 0.00 | TPTP20R | TP20R
TP15 | 41.09 | 23.52 | 0.00 | TPTP20R | TP20R
TP16 | 158.74 | 39.52 | 0.00 | TPTP20R | TP20R
TP17 | 62.39 | 62.52 | 0.00 | TPTP20R | TP20R
TP2 | 14.88 | 53.52 | 0.00 | TPTP20R | TP20R
TP3 | 96.80 | 54.52 | 0.00 | TPTP20R | TP20R
TP4 | 3.72 | 102.52 | 0.00 | TPTP20R | TP20R
TP5 | 35.64 | 3.52 | 0.00 | TPTP20R | TP20R
TP6 | 100.56 | 36.52 | 0.00 | TPTP20R | TP20R
TP7 | 49.48 | 19.52 | 0.00 | TPTP20R | TP20R
TP8 | 32.49 | 51.60 | 0.00 | TPTP20R | TP20R
TP9 | 51.41 | 50.60 | 0.00 | TPTP20R | TP20R
USBC-ESD | 151.97 | 54.30 | 180.00 | USBLC6-2SC6Y | SOT95P280X145-6N
USBC-ESD1 | 163.24 | 54.30 | 90.00 | SAMACSYS_PARTS_USB4110-GF-A | SAMACSYS_PARTS_USB4110GFA
VOL-SUPER | 29.91 | 92.29 | 270.00 | VOL-SUPER-RES | SOT95P280X125-5N

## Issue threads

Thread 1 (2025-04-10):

Lipseste LICENSE

R-Alexandra, 2025-04-10:
Ar trebui sa alegi o licenta open-source, de exemplu GNU sau Apache, si sa o adaugi repository-ului tau. Aceasta este necesara pentru a defini in mod clar drepturile altora de utilizare ale proiectului. Pentru mai multe informatii poti apasa [aici](https://docs.github.com/en/repositories/managing-your-repositorys-settings-and-features/customizing-your-repository/licensing-a-repository).

Closed 2025-04-15.

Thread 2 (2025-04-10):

Warnings Schematic - Layer incorect

R-Alexandra, 2025-04-10:
Am observat cateva warning-uri in fisierul schematic:

- Unul dintre ele este dat de utilizarea layer-ului "Nets" pentru liniile dintre componente si pentru titluri, care ar fi trebuit plasate pe layer-ul "Info" - il poti rezolva schimband layer-ul in cel corespunzator;
- Celelalte warning-uri pot fi aprobate, deoarece nu reprezinta o problema.

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

Closed 2025-04-15.

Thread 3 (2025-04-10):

Probleme Board

R-Alexandra, 2025-04-10:
Am analizat partea de PCB si am observat ca sunt cateva aspecte importante care ar trebui sa le revizuiesti inainte de a continua cu proiectarea.

Closed 2025-04-15.

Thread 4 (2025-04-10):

Trasee de Alimentare - grosime

R-Alexandra, 2025-04-10:
Traseele de alimentare (de exemplu VUSB, VBUS, 3V3 etc.) rutate nu au grosimea necesara. Te rog sa le rutezi cu o grosime de 0.3mm, conform constrangerilor. Pentru a implementa acest aspect, poti crea un netclass nou din Design Manager in care sa adaugi aceste semnale si sa creezi apoi o regula cu grosimea ceruta ce se va aplica tuturor semnalelor continute de acest netclass.

Rutarea se va realiza dupa ce rezolvi acest aspect.

Closed 2025-04-15.

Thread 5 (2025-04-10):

Rutarea necesita revizuire

R-Alexandra, 2025-04-10:
Rutarea pare sa aiba aspect neadecvat, posibil pentru ca nu ai asteptat sa se finalizeze procesul de rutare in cazul in care aceasta a fost realizata cu Autorouter si este si incompleta. De aici sunt si o parte din erorile rezultate in urma rularii DRC-ului astfel ca ar trebui reluata si asteptat pana se finalizeaza complet. Daca in urma finalizarii complete nu apare 100% rutat atunci va trebui sa rutezi manual traseele ramase.
De asemenea, nu trebuie rutate semnale pe sub antena modulului ESP32 - trebuie sa te asiguri si ca este decupata suprafata de sub antena pentru a crea cat mai putine interferente radio. O pozitionare mai buna a componentelor pe placuta poate ajuta la procesul de rutare, dar si la organizarea si aspectul per total al placii.

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

Closed 2025-04-15.

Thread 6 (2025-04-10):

Lipseste Plan de Masa

R-Alexandra, 2025-04-10:
La final, dupa ce rutarea este completa si validata, va trebui sa realizezi planul de masa - poti folosi optiunea Polygon pour. Daca rutarea s-a realizat pe ambele layere si planul de masa il vei realiza la fel.

Closed 2025-04-15.

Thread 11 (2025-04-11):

Fisier CPL Inlocuire

R-Alexandra, 2025-04-11:
Am observat ca fisierul incarcat in locul fisierului CPL (Pick and Place) este tot fisierul BOM. Este posibil sa fi fost o eroare de selectie la momentul incarcarii. Te rog sa verifici si sa inlocuiesti fisierul cu varianta corecta.

Closed 2025-04-15.

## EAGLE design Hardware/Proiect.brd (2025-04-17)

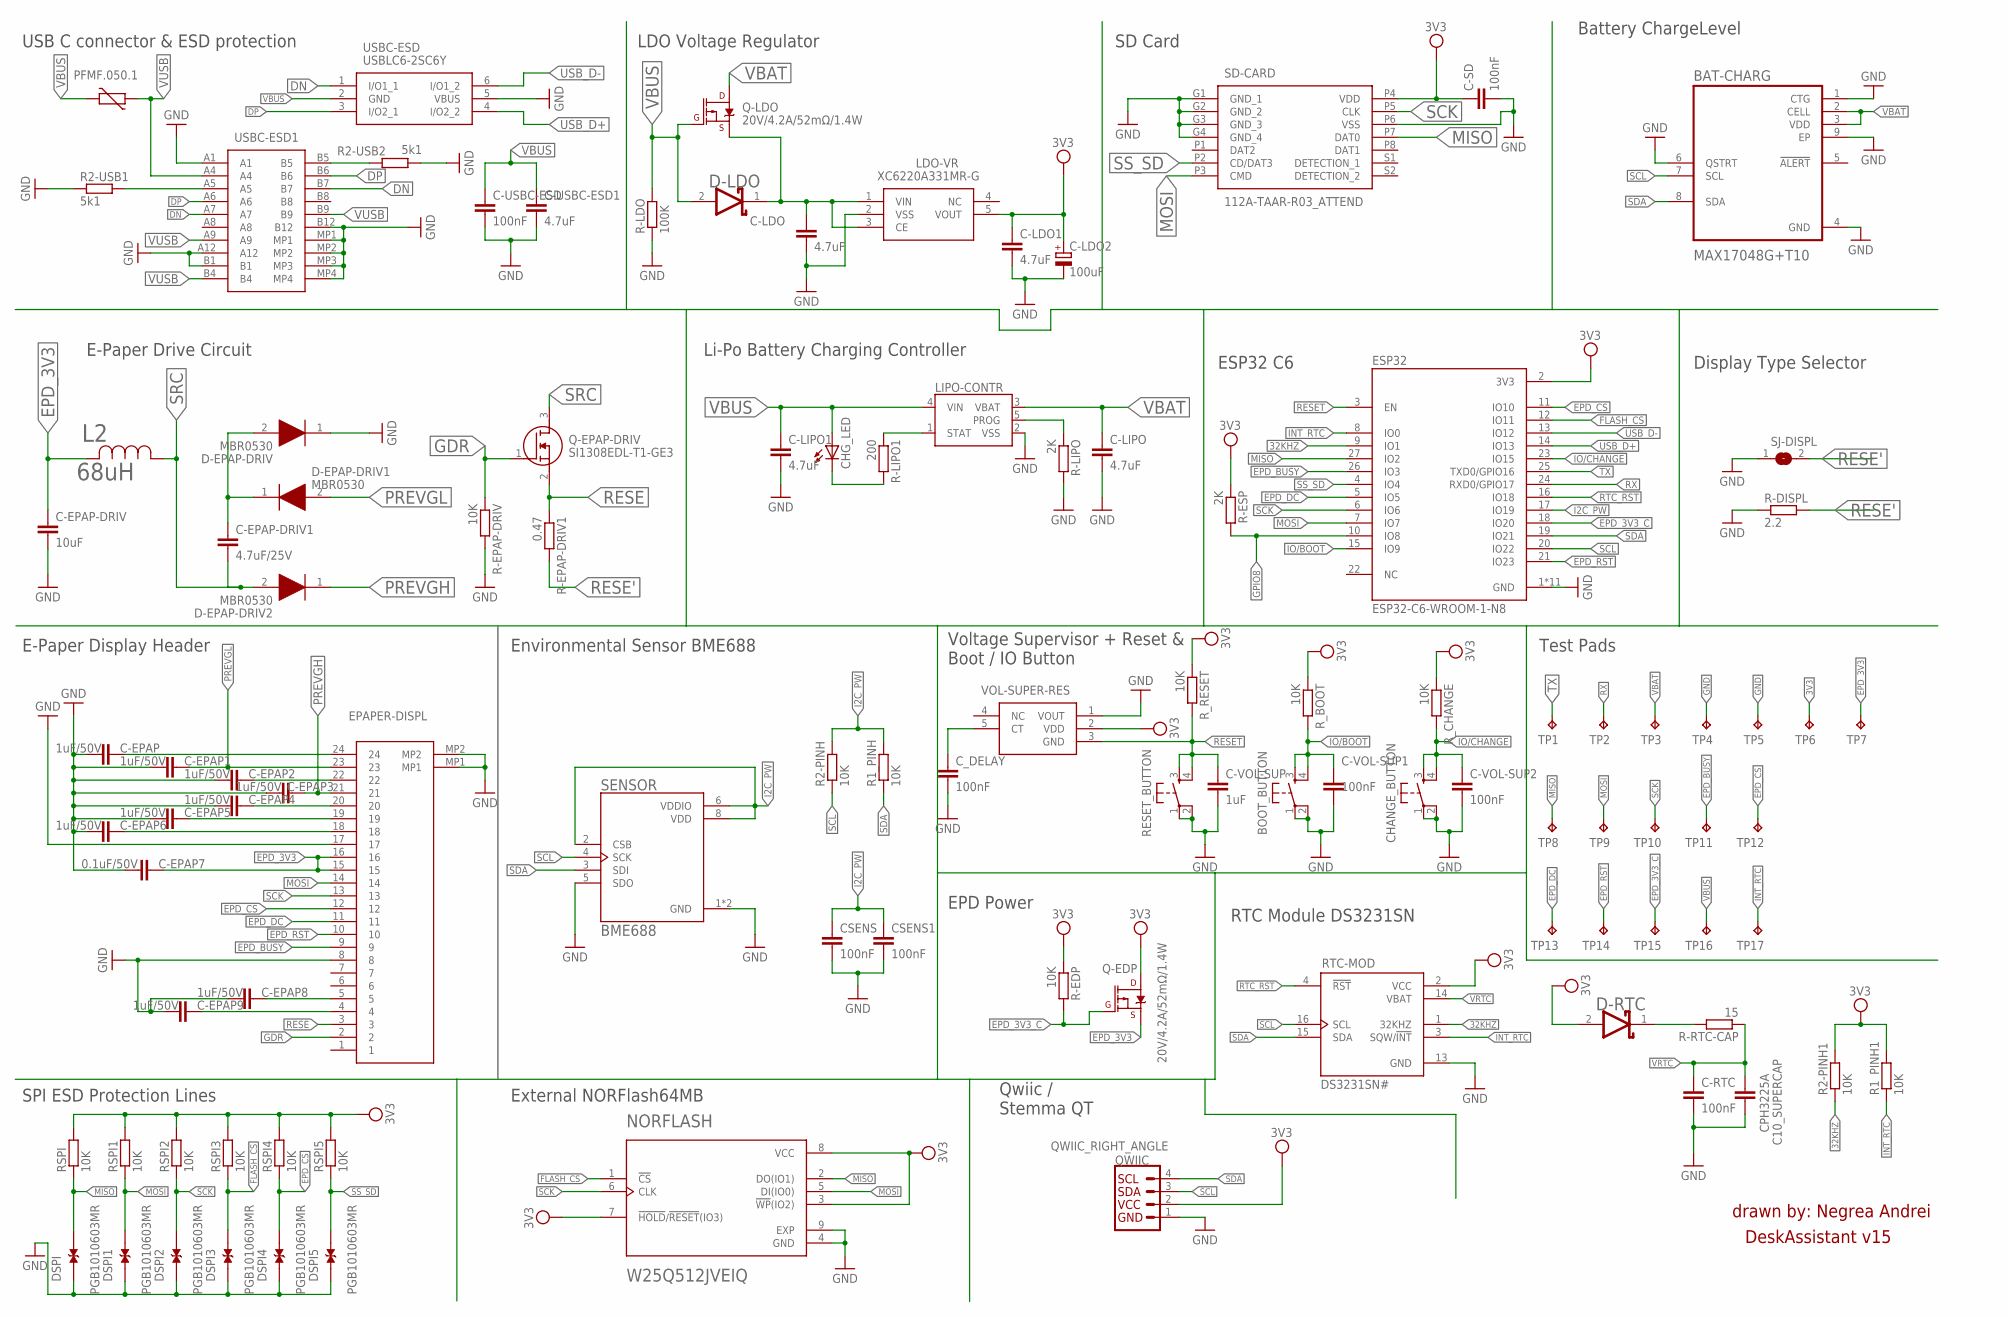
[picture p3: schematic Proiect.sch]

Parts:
BAT-CHARG: MAX17048G+T10; SON50P200X200X80-9N
BOOT_BUTTON: BOOT_BUTTON; MYBUTTON
C-EPAP, C-EPAP1, C-EPAP2, C-EPAP3, C-EPAP4, C-EPAP5, C-EPAP6, C-EPAP8, C-EPAP9: 1uF/50V; ESP32_WROVER_EAGLE-LTSPICE_C0402
C-EPAP7: 0.1uF/50V; ESP32_WROVER_EAGLE-LTSPICE_C0402
C-EPAP-DRIV: 10uF; ESP32_WROVER_EAGLE-LTSPICE_C0402
C-EPAP-DRIV1: 4.7uF/25V; ESP32_WROVER_EAGLE-LTSPICE_C0402
C-LDO, C-LDO1: 4.7uF; ESP32_WROVER_EAGLE-LTSPICE_C0402
C-LDO2: 100uF; RCL_CT3528
C-LIPO, C-LIPO1: 4.7uF; ESP32_WROVER_EAGLE-LTSPICE_C0402
C-RTC: 100nF; ESP32_WROVER_EAGLE-LTSPICE_C0402
C-SD: 100nF; ESP32_WROVER_EAGLE-LTSPICE_C0402
C-USBC-ESD: 100nF; ESP32_WROVER_EAGLE-LTSPICE_C0402
C-USBC-ESD1: 4.7uF; ESP32_WROVER_EAGLE-LTSPICE_C0402
C-VOL-SUP: 1uF; ESP32_WROVER_EAGLE-LTSPICE_C0402
C-VOL-SUP1, C-VOL-SUP2: 100nF; ESP32_WROVER_EAGLE-LTSPICE_C0402
CHANGE_BUTTON: CHANGE_BUTTON; MYBUTTON
CHG_LED: ADAFRUIT_LEDCHIP-LED0603; ADAFRUIT_CHIP-LED0603
CPH3225A: C10_SUPERCAP; ESP32_WROVER_EAGLE-LTSPICE_C0402
CSENS, CSENS1: 100nF; ESP32_WROVER_EAGLE-LTSPICE_C0402
C_DELAY: 100nF; ESP32_WROVER_EAGLE-LTSPICE_C0402
D-EPAP-DRIV, D-EPAP-DRIV1, D-EPAP-DRIV2: MBR0530; SOD3716X135N
D-LDO: ESP32_WROVER_AVX---SD0805S020S1R0_AVX_SD0805S020S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; ESP32_WROVER_AVX---SD0805S020S1R0_AVX_SD0805S020S1R0_0
D-RTC: ESP32_WROVER_AVX---SD0805S020S1R0_AVX_SD0805S020S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; ESP32_WROVER_AVX---SD0805S020S1R0_AVX_SD0805S020S1R0_0
DSPI, DSPI1, DSPI2, DSPI3, DSPI4, DSPI5: PGB1010603MR; DIOC1608X36N
EPAPER-DISPL: FH34SRJ-24S-0.5SH_99_; FH34SRJ24S05SH99
ESP32: ESP32-C6-WROOM-1-N8; XCVR_ESP32-C6-WROOM-1-N8
L2: 68uH; IND_4828-WE-TPC_WRE
LDO-VR: XC6220A331MR-G; SOT95P280X120-5N
LIPO-CONTR: ESP32_WROVER_SPARKFUN-IC-POWER_MCP73831; ESP32_WROVER_SPARKFUN-IC-POWER_SOT23-5
NORFLASH: W25Q512JVEIQ; SON127P600X800X80-9N
PFMF.050.1: ESP32C6_VARISTORCN1812; ESP32C6_VARISTOR_CT/CN1812
Q-EDP: 20V/4.2A/52mΩ/1.4W; ESP32_WROVER_SPARKFUN-DISCRETESEMI_SOT23-3
Q-EPAP-DRIV: SI1308EDL-T1-GE3; SOT65P210X110-3N
Q-LDO: 20V/4.2A/52mΩ/1.4W; ESP32_WROVER_SPARKFUN-DISCRETESEMI_SOT23-3
QWIIC: QWIIC_RIGHT_ANGLE; JST04_1MM_RA
R1_PINH, R1_PINH1, R2-PINH, R2-PINH1: 10K; ESP32_WROVER_EAGLE-LTSPICE_R0402
R2-USB1, R2-USB2: 5k1; ESP32_WROVER_EAGLE-LTSPICE_R0402
R-DISPL: 2.2; ESP32_WROVER_EAGLE-LTSPICE_R0402
R-EDP: 10K; ESP32_WROVER_EAGLE-LTSPICE_R0402
R-EPAP-DRIV: 10K; ESP32_WROVER_EAGLE-LTSPICE_R0402
R-EPAP-DRIV1: 0.47; ESP32_WROVER_EAGLE-LTSPICE_R0402
R-ESP: 2K; ESP32_WROVER_EAGLE-LTSPICE_R0402
R-LDO: 100K; ESP32_WROVER_EAGLE-LTSPICE_R0402
R-LIPO: 2K; ESP32_WROVER_EAGLE-LTSPICE_R0402
R-LIPO1: 200; ESP32_WROVER_EAGLE-LTSPICE_R0402
R-RTC-CAP: 15; ESP32_WROVER_EAGLE-LTSPICE_R0402
RESET_BUTTON: RESET_BUTTON; MYBUTTON
RSPI, RSPI1, RSPI2, RSPI3, RSPI4, RSPI5: 10K; ESP32_WROVER_EAGLE-LTSPICE_R0402
RTC-MOD: DS3231SN#; SOIC127P1032X265-16N
R_BOOT: 10K; ESP32_WROVER_EAGLE-LTSPICE_R0402
R_CHANGE: 10K; ESP32_WROVER_EAGLE-LTSPICE_R0402
R_RESET: 10K; ESP32_WROVER_EAGLE-LTSPICE_R0402
SD-CARD: 112A-TAAR-R03_ATTEND; 112ATAARR03ATTEND
SENSOR: BME688; ESP32_WROVER_BME680_PSON80P300X300X100-8N
SJ-DISPL: SJ
TP1, TP2, TP3, TP4, TP5, TP6, TP7, TP8, TP9, TP10, TP11, TP12, TP13, TP14, TP15, TP16, TP17: TPTP20R; TP20R
USBC-ESD: USBLC6-2SC6Y; SOT95P280X145-6N
USBC-ESD1: SAMACSYS_PARTS_USB4110-GF-A; SAMACSYS_PARTS_USB4110GFA
VOL-SUPER: VOL-SUPER-RES; SOT95P280X125-5N

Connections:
3V3: C-LDO1.1, C-LDO2.+, C-SD.1, D-RTC.2 (ANODE), ESP32.2 (3V3), LDO-VR.5 (VOUT), NORFLASH.3 (!WP!(IO2)), NORFLASH.7 (!HOLD!/!RESET!(IO3)), NORFLASH.8 (VCC), Q-EDP.3 (D), QWIIC.2, R1_PINH1.2, R2-PINH1.2, R-EDP.1, R-ESP.1, RSPI.2, RSPI1.2, RSPI2.2, RSPI3.2, RSPI4.2, RSPI5.2, RTC-MOD.2 (VCC), R_BOOT.1, R_CHANGE.1, R_RESET.1, SD-CARD.P4 (VDD), TP6.TP, VOL-SUPER.2 (VDD)
32KHZ: ESP32.9 (IO1), R2-PINH1.1, RTC-MOD.1 (32KHZ)
DN: USBC-ESD.1 (I/O1_1), USBC-ESD1.A7, USBC-ESD1.B7
DP: USBC-ESD.3 (I/O2_1), USBC-ESD1.A6, USBC-ESD1.B6
EPD_3V3: C-EPAP7.1, C-EPAP-DRIV.1, EPAPER-DISPL.15, EPAPER-DISPL.16, L2.2, Q-EDP.2 (S), TP7.TP
EPD_3V3_C: ESP32.18 (IO20), Q-EDP.1 (G), R-EDP.2, TP15.TP
EPD_BUSY: EPAPER-DISPL.9, ESP32.26 (IO3), TP11.TP
EPD_CS: DSPI4.2, EPAPER-DISPL.12, ESP32.11 (IO10), RSPI4.1, TP12.TP
EPD_DC: EPAPER-DISPL.11, ESP32.5 (IO5), TP13.TP
EPD_RST: EPAPER-DISPL.10, ESP32.21 (IO23), TP14.TP
FLASH_CS: DSPI3.2, ESP32.12 (IO11), NORFLASH.1 (!CS), RSPI3.1
GDR: EPAPER-DISPL.2, Q-EPAP-DRIV.1 (G), R-EPAP-DRIV.1
GND: BAT-CHARG.1 (CTG), BAT-CHARG.4 (GND), BAT-CHARG.6 (QSTRT), BAT-CHARG.9 (EP), BOOT_BUTTON.1, BOOT_BUTTON.2, C-EPAP.2, C-EPAP1.2, C-EPAP2.2, C-EPAP3.2, C-EPAP4.2, C-EPAP5.2, C-EPAP6.2, C-EPAP7.2, C-EPAP8.2, C-EPAP9.2, C-EPAP-DRIV.2, C-LDO.2, C-LDO1.2, C-LDO2.-, C-LIPO.2, C-LIPO1.2, C-RTC.2, C-SD.2, C-USBC-ESD.2, C-USBC-ESD1.2, C-VOL-SUP.2, C-VOL-SUP1.2, C-VOL-SUP2.2, CHANGE_BUTTON.1, CHANGE_BUTTON.2, CPH3225A.2, CSENS.2, CSENS1.2, C_DELAY.2, D-EPAP-DRIV.1 (K), DSPI.1, DSPI1.1, DSPI2.1, DSPI3.1, DSPI4.1, DSPI5.1, EPAPER-DISPL.8, EPAPER-DISPL.17, EPAPER-DISPL.MP1, EPAPER-DISPL.MP2, ESP32.1 (GND), ESP32.28 (GND), ESP32.29_1 (GND), ESP32.29_2 (GND), ESP32.29_3 (GND), ESP32.29_4 (GND), ESP32.29_5 (GND), ESP32.29_6 (GND), ESP32.29_7 (GND), ESP32.29_8 (GND), ESP32.29_9 (GND), LDO-VR.2 (VSS), LIPO-CONTR.2 (VSS), NORFLASH.4 (GND), NORFLASH.9 (EXP), QWIIC.1, R2-USB1.1, R2-USB2.2, R-DISPL.1, R-EPAP-DRIV.2, R-LDO.1, R-LIPO.2, RESET_BUTTON.1, RESET_BUTTON.2, RTC-MOD.13 (GND), SD-CARD.G1 (GND_1), SD-CARD.G2 (GND_2), SD-CARD.G3 (GND_3), SD-CARD.G4 (GND_4), SD-CARD.P6 (VSS), SENSOR.1 (GND), SENSOR.5 (SDO), SENSOR.7 (GND), SJ-DISPL.1, TP4.TP, TP5.TP, USBC-ESD.5 (VBUS), USBC-ESD1.A1, USBC-ESD1.A12, USBC-ESD1.B1, USBC-ESD1.B12, USBC-ESD1.MP1, USBC-ESD1.MP2, USBC-ESD1.MP3, USBC-ESD1.MP4, VOL-SUPER.1 (VOUT)
GPIO8: ESP32.10 (IO8), R-ESP.2
I2C_PW: CSENS.1, CSENS1.1, ESP32.17 (IO19), R1_PINH.2, R2-PINH.2, SENSOR.2 (CSB), SENSOR.6 (VDDIO), SENSOR.8 (VDD)
INT_RTC: ESP32.8 (IO0), R1_PINH1.1, RTC-MOD.3 (SQW/!INT), TP17.TP
IO/BOOT: BOOT_BUTTON.3, BOOT_BUTTON.4, C-VOL-SUP1.1, ESP32.15 (IO9), R_BOOT.2
IO/CHANGE: C-VOL-SUP2.1, CHANGE_BUTTON.3, CHANGE_BUTTON.4, ESP32.23 (IO15), R_CHANGE.2
MISO: DSPI.2, ESP32.27 (IO2), NORFLASH.2 (DO(IO1)), RSPI.1, SD-CARD.P7 (DAT0), TP8.TP
MOSI: DSPI1.2, EPAPER-DISPL.14, ESP32.7 (IO7), NORFLASH.5 (DI(IO0)), RSPI1.1, SD-CARD.P3 (CMD), TP9.TP
unnamed: R2-USB1.2, USBC-ESD1.A5
unnamed: R2-USB2.1, USBC-ESD1.B5
unnamed: C-EPAP.1, EPAPER-DISPL.24
unnamed: CHG_LED.C, R-LIPO1.2
unnamed: LIPO-CONTR.1 (STAT), R-LIPO1.1
unnamed: LIPO-CONTR.5 (PROG), R-LIPO.1
unnamed: C-EPAP2.1, EPAPER-DISPL.22
unnamed: C-EPAP-DRIV1.1, D-EPAP-DRIV.2 (A), D-EPAP-DRIV1.1 (K)
unnamed: C-EPAP4.1, EPAPER-DISPL.20
unnamed: C-EPAP5.1, EPAPER-DISPL.19
unnamed: C-EPAP6.1, EPAPER-DISPL.18
unnamed: C_DELAY.1, VOL-SUPER.5 (CT)
unnamed: C-EPAP8.1, EPAPER-DISPL.5
unnamed: C-EPAP9.1, EPAPER-DISPL.4
unnamed: C-LDO.1, D-LDO.1 (CATHODE), LDO-VR.1 (VIN), LDO-VR.3 (CE), Q-LDO.2 (S)
unnamed: D-RTC.1 (CATHODE), R-RTC-CAP.2
PREVGH: C-EPAP3.1, D-EPAP-DRIV2.1 (K), EPAPER-DISPL.21
PREVGL: C-EPAP1.1, D-EPAP-DRIV1.2 (A), EPAPER-DISPL.23
RESE: EPAPER-DISPL.3, Q-EPAP-DRIV.2 (S), R-EPAP-DRIV1.1
RESE': R-DISPL.2, R-EPAP-DRIV1.2, SJ-DISPL.2
RESET: C-VOL-SUP.1, ESP32.3 (EN), RESET_BUTTON.3, RESET_BUTTON.4, R_RESET.2, VOL-SUPER.3 (GND)
RTC_RST: ESP32.16 (IO18), RTC-MOD.4 (!RST)
RX: ESP32.24 (RXD0/GPIO17), TP2.TP
SCK: DSPI2.2, EPAPER-DISPL.13, ESP32.6 (IO6), NORFLASH.6 (CLK), RSPI2.1, SD-CARD.P5 (CLK), TP10.TP
SCL: BAT-CHARG.7 (SCL), ESP32.20 (IO22), QWIIC.3, R2-PINH.1, RTC-MOD.16 (SCL), SENSOR.4 (SCK)
SDA: BAT-CHARG.8 (SDA), ESP32.19 (IO21), QWIIC.4, R1_PINH.1, RTC-MOD.15 (SDA), SENSOR.3 (SDI)
SRC: C-EPAP-DRIV1.2, D-EPAP-DRIV2.2 (A), L2.1, Q-EPAP-DRIV.3 (D)
SS_SD: DSPI5.2, ESP32.4 (IO4), RSPI5.1, SD-CARD.P2 (CD/DAT3)
TX: ESP32.25 (TXD0/GPIO16), TP1.TP
USB_D+: ESP32.14 (IO13), USBC-ESD.4 (I/O2_2)
USB_D-: ESP32.13 (IO12), USBC-ESD.6 (I/O1_2)
VBAT: BAT-CHARG.2 (CELL), BAT-CHARG.3 (VDD), C-LIPO.1, LIPO-CONTR.3 (VBAT), Q-LDO.3 (D), TP3.TP
VBUS: C-LIPO1.1, C-USBC-ESD.1, C-USBC-ESD1.1, CHG_LED.A, D-LDO.2 (ANODE), LIPO-CONTR.4 (VIN), PFMF.050.1.2, Q-LDO.1 (G), R-LDO.2, TP16.TP, USBC-ESD.2 (GND)
VRTC: C-RTC.1, CPH3225A.1, R-RTC-CAP.1, RTC-MOD.14 (VBAT)
VUSB: PFMF.050.1.1, USBC-ESD1.A4, USBC-ESD1.A9, USBC-ESD1.B4, USBC-ESD1.B9

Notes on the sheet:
USB C connector & ESD protection
LDO Voltage Regulator
SD Card
Display Type Selector
E-Paper Drive Circuit
Li-Po Battery Charging Controller
ESP32 C6
E-Paper Display Header
EPD Power
Environmental Sensor BME688
Voltage Supervisor + Reset & Boot / IO Button
Battery ChargeLevel
RTC Module DS3231SN
Test Pads
Qwiic / Stemma QT
SPI ESD Protection Lines
External NORFlash64MB
drawn by: Negrea Andrei
DeskAssistant v15

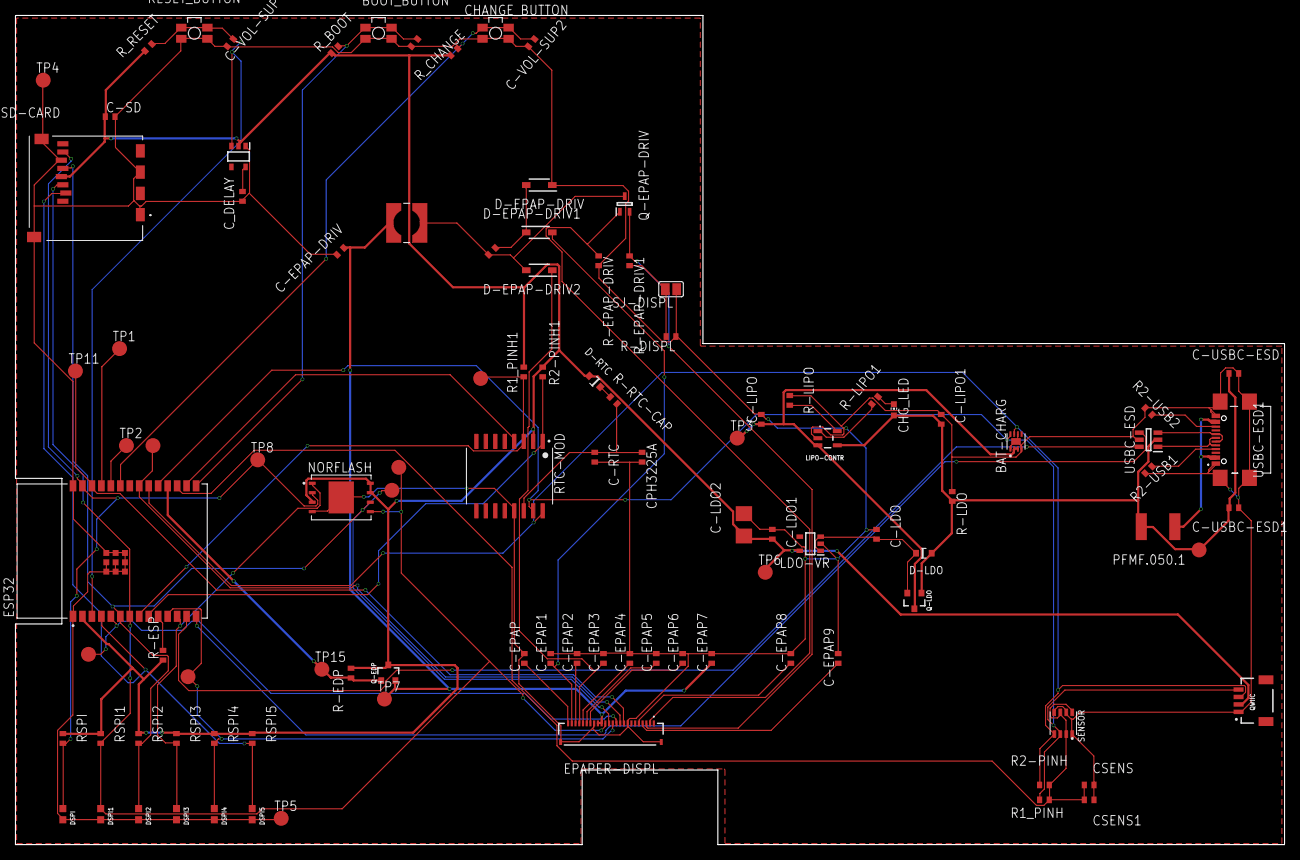
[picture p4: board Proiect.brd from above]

Board: 2 copper layers, 170.2 x 111.2 mm, 103 parts (0 on the bottom side), 55 nets.

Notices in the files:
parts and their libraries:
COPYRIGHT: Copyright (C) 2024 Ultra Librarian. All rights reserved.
